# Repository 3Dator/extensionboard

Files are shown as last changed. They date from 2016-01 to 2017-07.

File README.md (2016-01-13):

3Dator extensionboard firmware
======

This repository contains the firmware for our tiny extensionboard that is used to drive the LEDs and both Fans.

Also there is a voltage devider for the 12V Feedback pin of the inductive z probe.

For more information visit our website or wiki:

http://3dator.com

http://wiki.3dator.com

#how to use
If you want to play arrount with the sourcecode on your board you need a ISP Programmer which is supported by Arduino IDE. (e.g. stk 500)

#License
Please note that the material in this repository is licensed with the CC BY-NC-SA

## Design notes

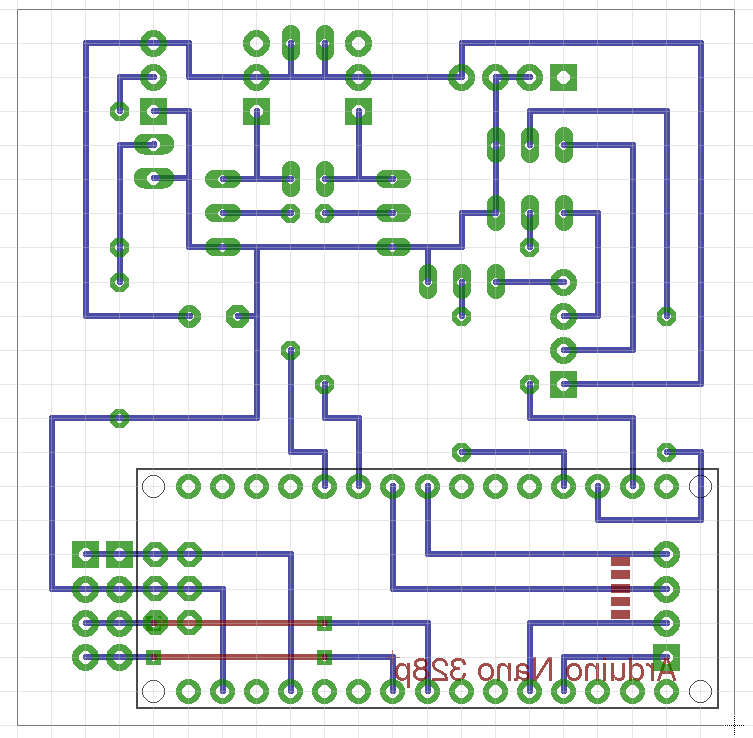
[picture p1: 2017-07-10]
PCB Files/diy PCBs/Analog/diy_analog_Layout_wires_mirrored.png

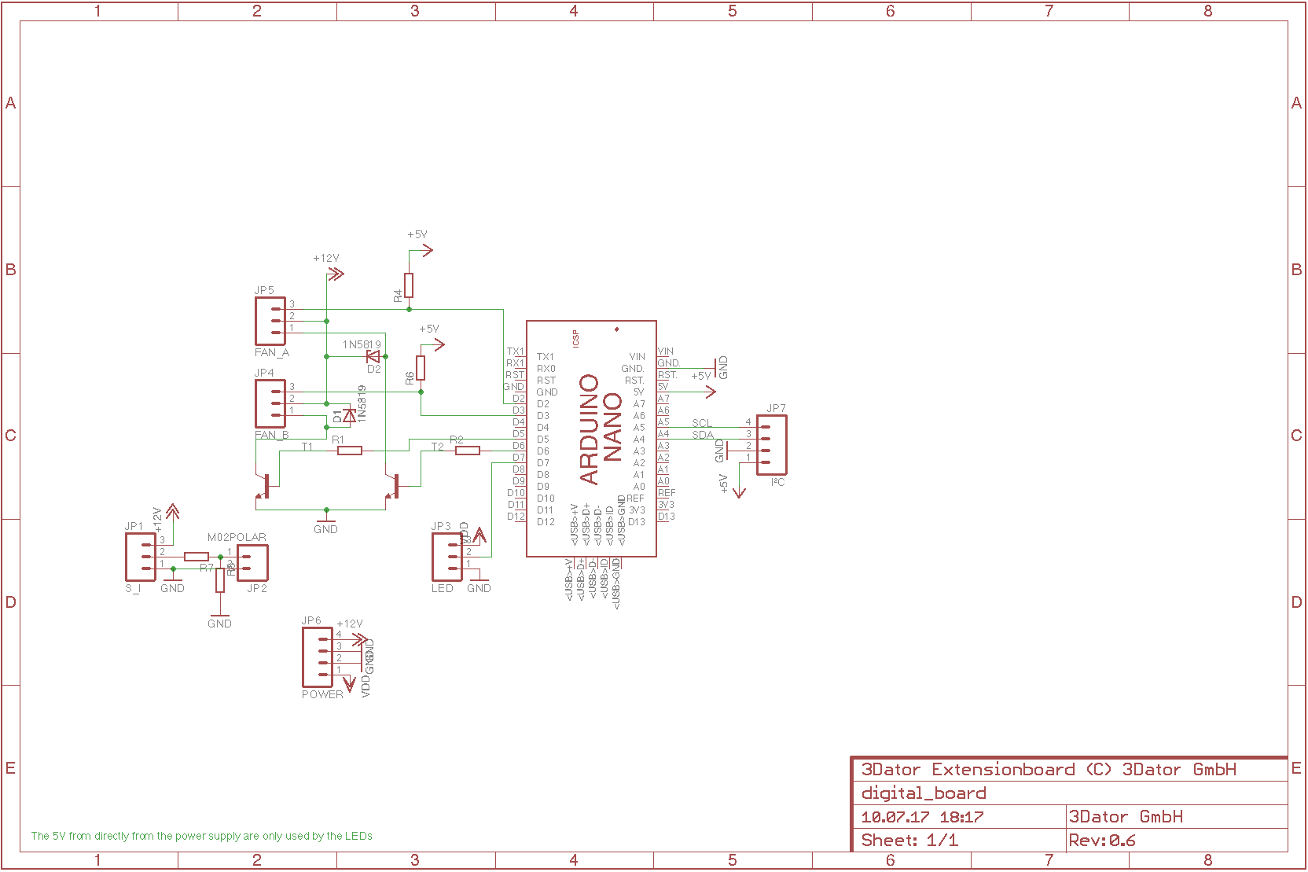
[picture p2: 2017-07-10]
PCB Files/diy PCBs/Digital/diy_digital_pcb.png

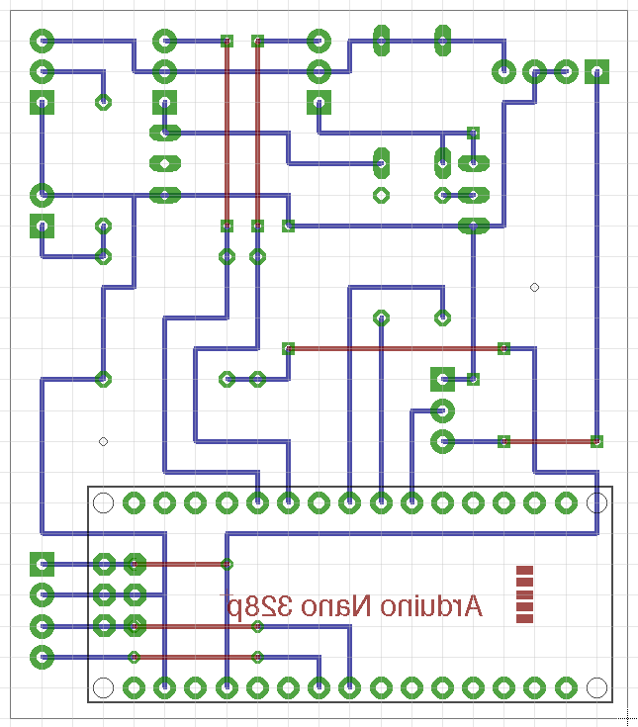
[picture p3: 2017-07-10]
PCB Files/diy PCBs/Digital/diy_digital_Layout_wires_mirrored.png

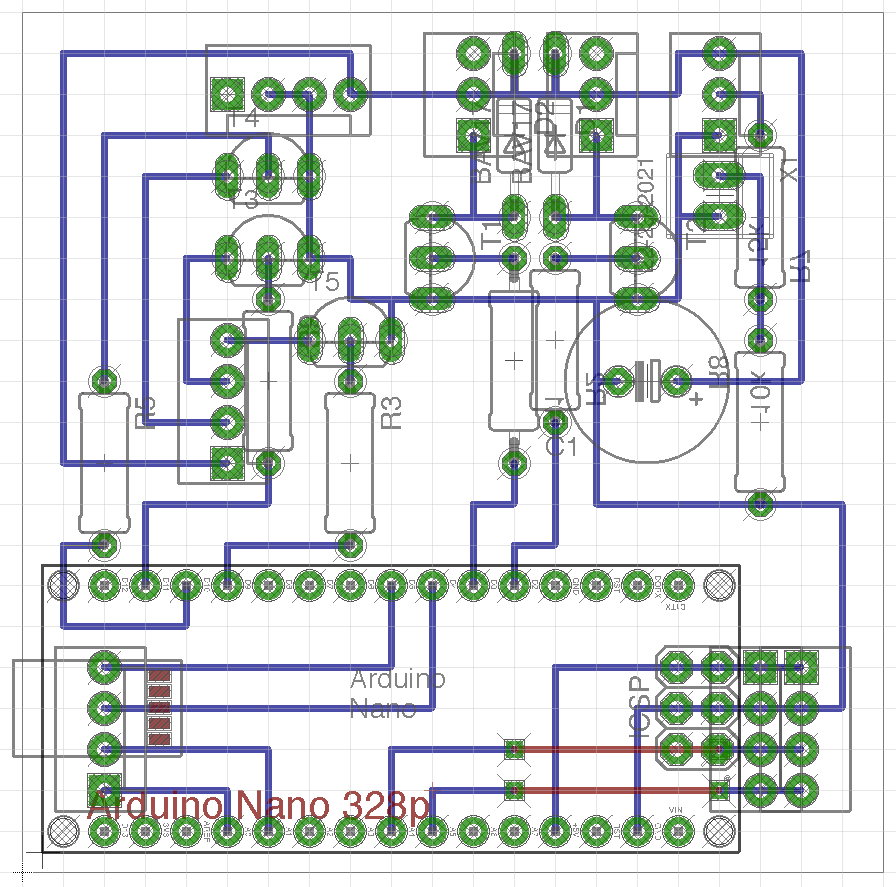
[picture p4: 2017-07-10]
PCB Files/diy PCBs/Analog/diy_analog_Layout.png

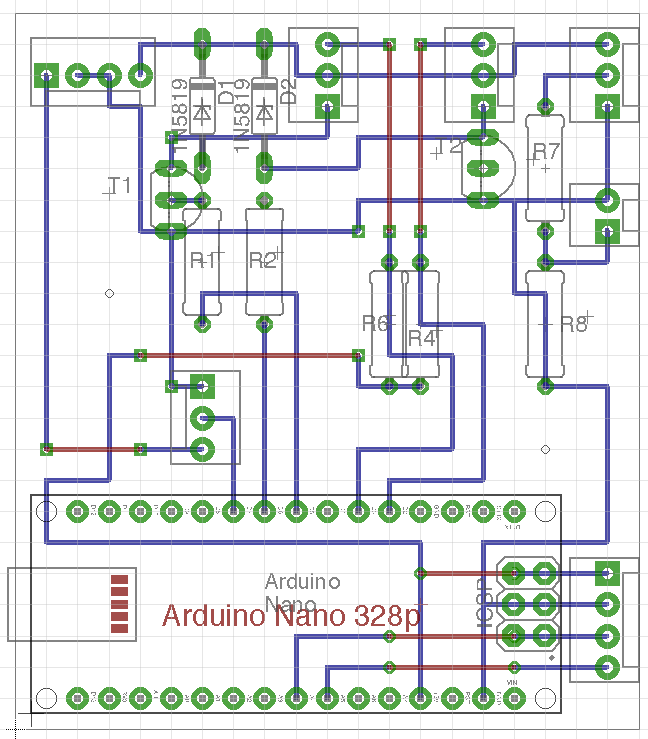
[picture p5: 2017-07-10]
PCB Files/diy PCBs/Digital/diy_digital_Layout.png

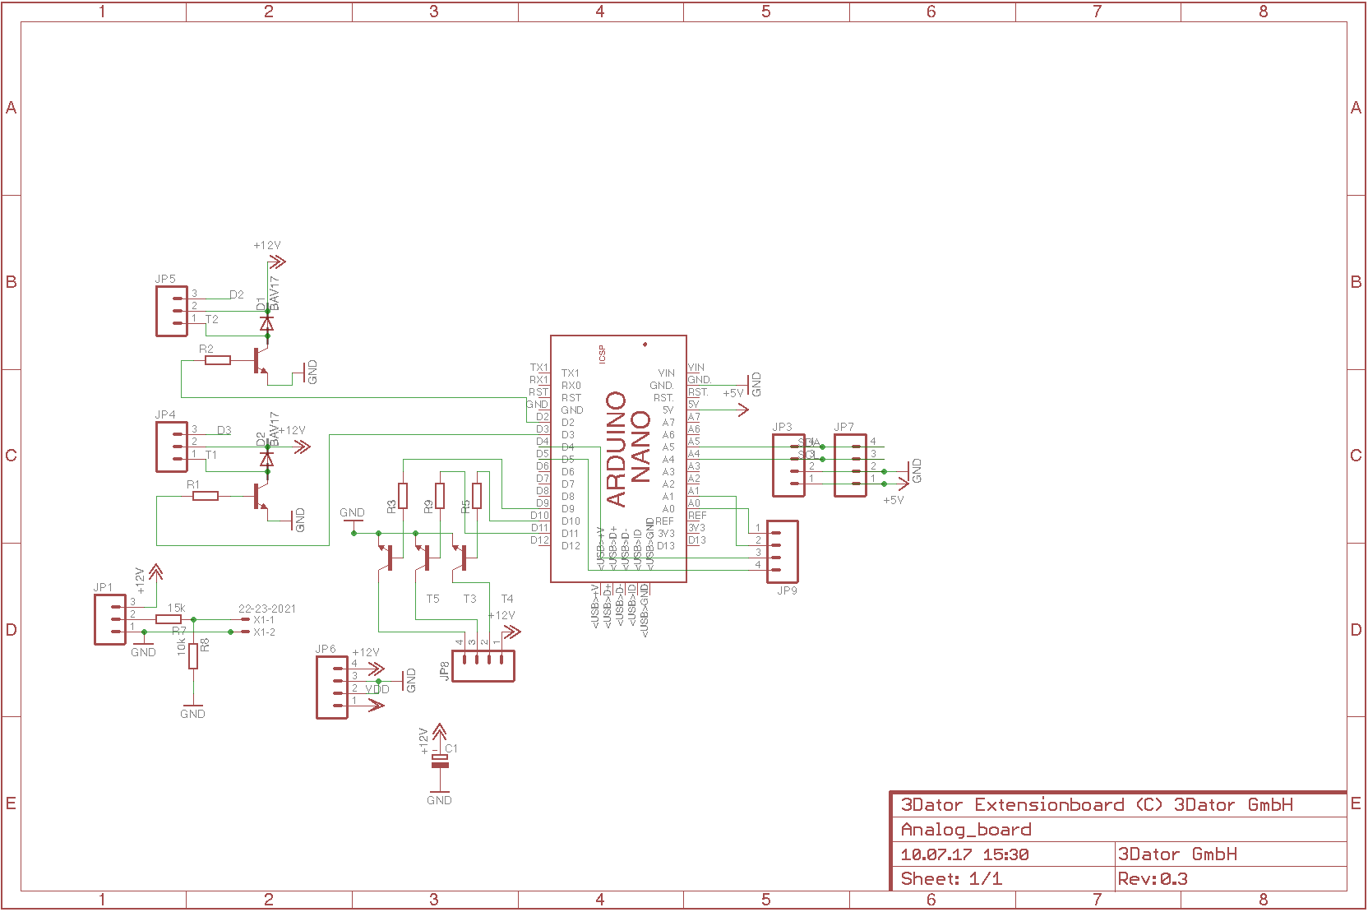
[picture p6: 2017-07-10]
PCB Files/diy PCBs/Analog/diy_analog_pcb.png

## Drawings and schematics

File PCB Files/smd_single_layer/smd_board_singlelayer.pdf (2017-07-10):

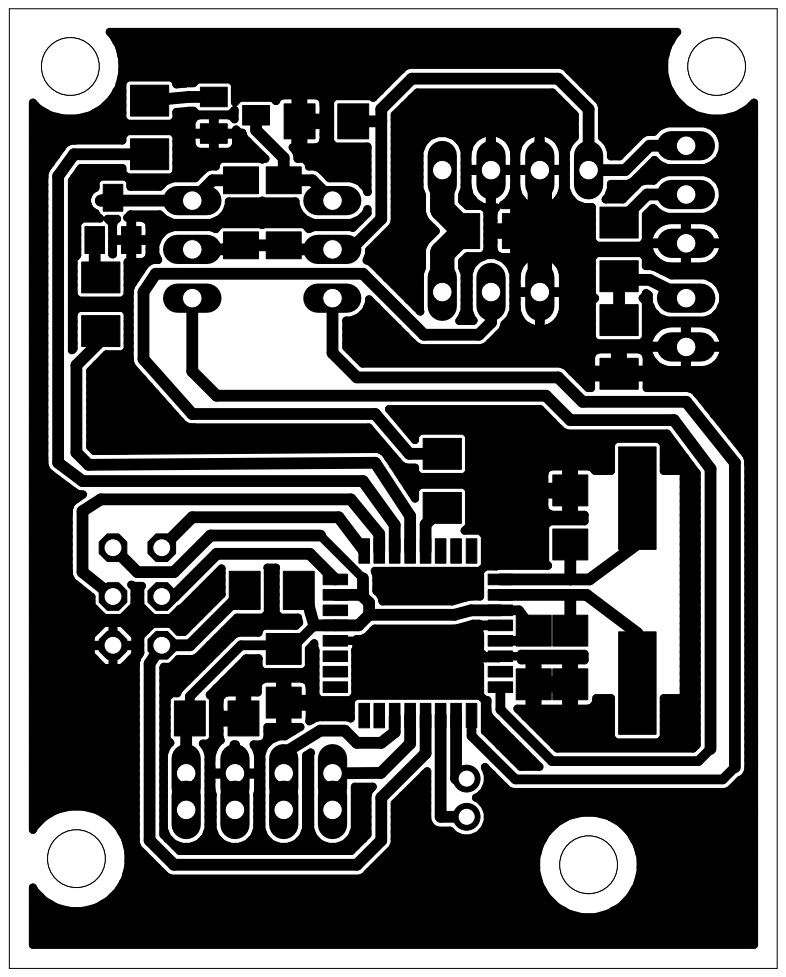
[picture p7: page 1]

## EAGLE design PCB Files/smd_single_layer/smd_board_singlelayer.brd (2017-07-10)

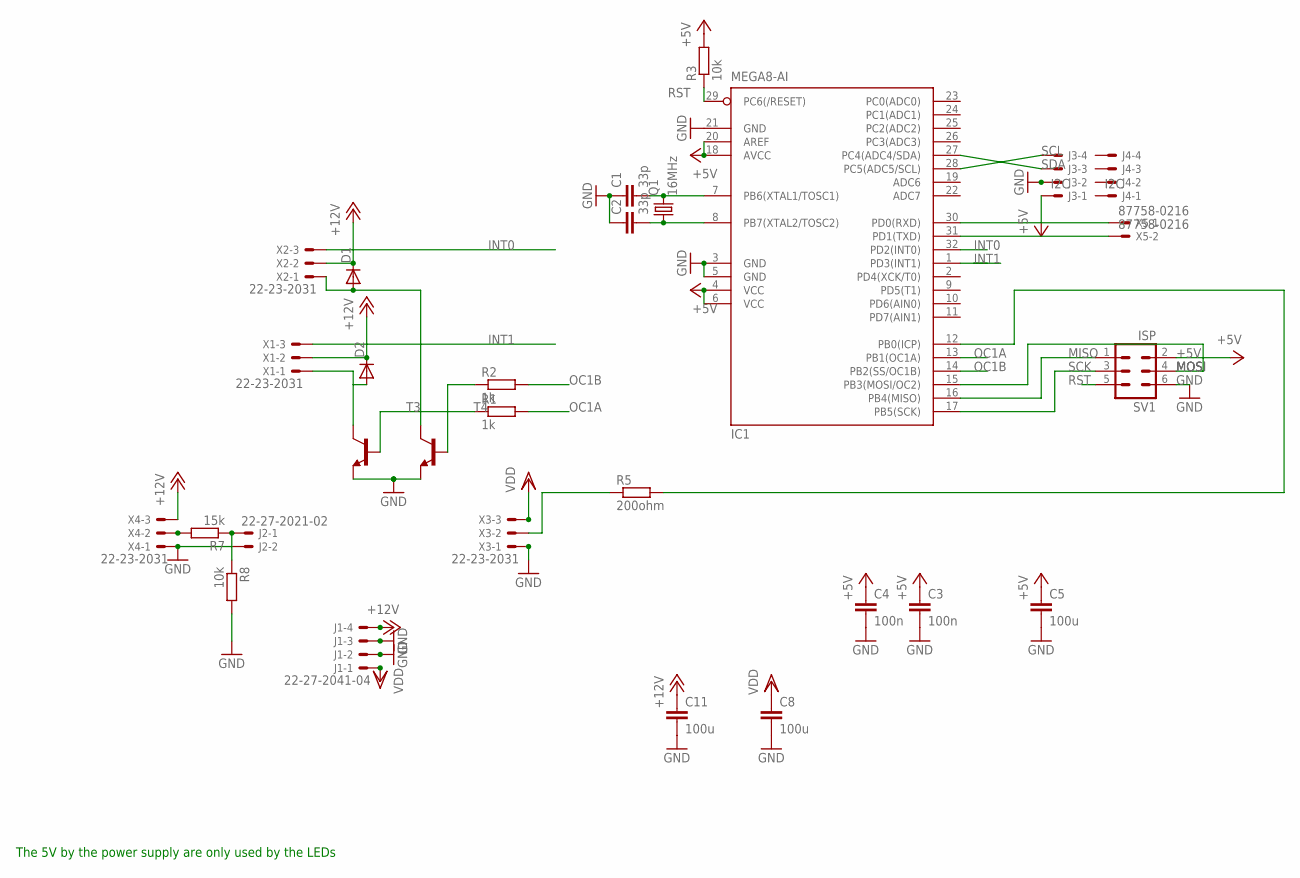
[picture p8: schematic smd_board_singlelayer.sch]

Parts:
C1, C2: 33p; C1206
C3, C4: 100n; C1206
C5, C8, C11: 100u; C1206
D1, D2: DIODE-SOD80C; SOD80C
IC1: MEGA8-AI; TQFP32-08
J1: 22-27-2041-04; 6410-04
J2: 22-27-2021-02; 6410-02
J3, J4: I2C; 6410-04
Q1: 16MHz; HC49UP
R1, R2: 1k; M1206
R3, R8: 10k; M1206
R5: 200ohm; M1206
R7: 15k; M1206
SV1: ISP; ML6
T3, T4: BC808-NPN-SOT23-BEC; SOT23-BEC
X1, X2, X3, X4: 22-23-2031
X5: 87758-0216

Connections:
+5V: C3.1, C4.1, C5.1, IC1.4 (VCC), IC1.6 (VCC), IC1.18 (AVCC), IC1.20 (AREF), J3.1, R3.2, SV1.2
+12V: C11.1, D1.C, D2.C, J1.4, X1.2, X2.2, X4.3
GND: C1.1, C2.1, C3.2, C4.2, C5.2, C8.2, C11.2, IC1.3 (GND), IC1.5 (GND), IC1.21 (GND), J1.2, J1.3, J2.2, J3.2, R8.2, SV1.6, T3.E, T4.E, X3.1, X4.1
INT0: IC1.32 (PD2(INT0)), X2.3
INT1: IC1.1 (PD3(INT1)), X1.3
MISO: IC1.16 (PB4(MISO)), SV1.1
MOSI: IC1.15 (PB3(MOSI/OC2)), SV1.4
unnamed: C1.2, IC1.7 (PB6(XTAL1/TOSC1)), Q1.2
unnamed: D2.A, T3.C, X1.1
unnamed: D1.A, T4.C, X2.1
unnamed: R2.1, T4.B
unnamed: R1.1, T3.B
unnamed: R5.1, X3.2
unnamed: C2.2, IC1.8 (PB7(XTAL2/TOSC2)), Q1.1
unnamed: IC1.30 (PD0(RXD)), X5.1
unnamed: R7.2, X4.2
unnamed: J2.1, R7.1, R8.1
unnamed: IC1.12 (PB0(ICP)), R5.2
unnamed: IC1.31 (PD1(TXD)), X5.2
OC1A: IC1.13 (PB1(OC1A)), R1.2
OC1B: IC1.14 (PB2(SS/OC1B)), R2.2
RST: IC1.29 (PC6(/RESET)), R3.1, SV1.5
SCK: IC1.17 (PB5(SCK)), SV1.3
SCL: IC1.28 (PC5(ADC5/SCL)), J3.4
SDA: IC1.27 (PC4(ADC4/SDA)), J3.3
VDD: C8.1, J1.1, X3.3

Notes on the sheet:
The 5V by the power supply are only used by the LEDs

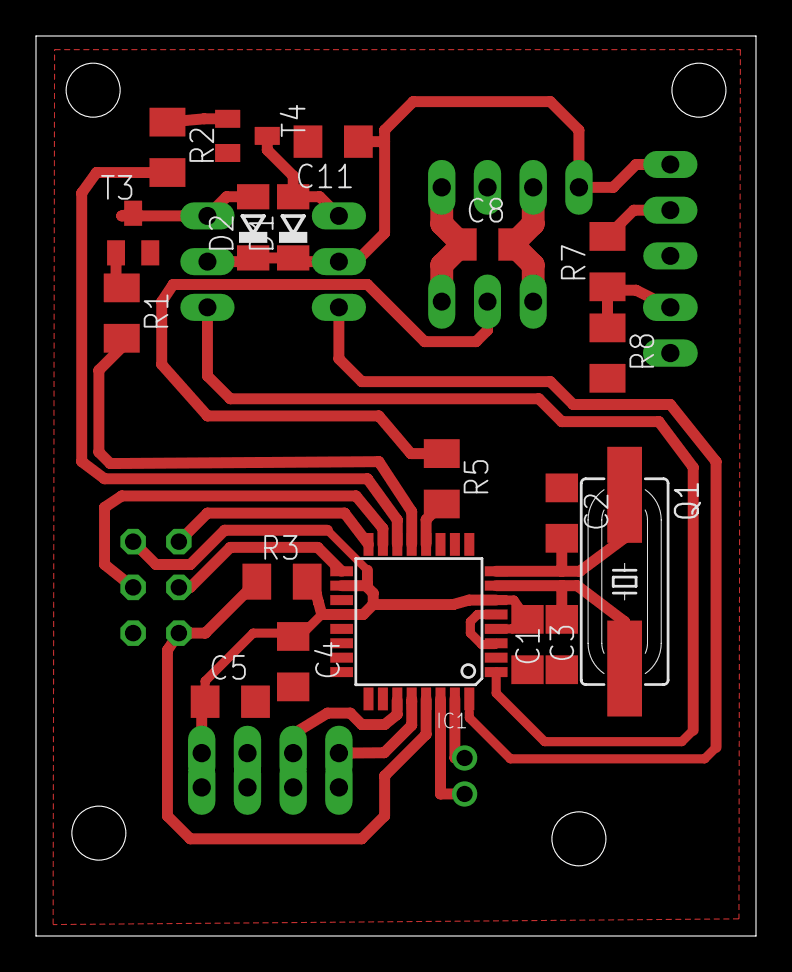
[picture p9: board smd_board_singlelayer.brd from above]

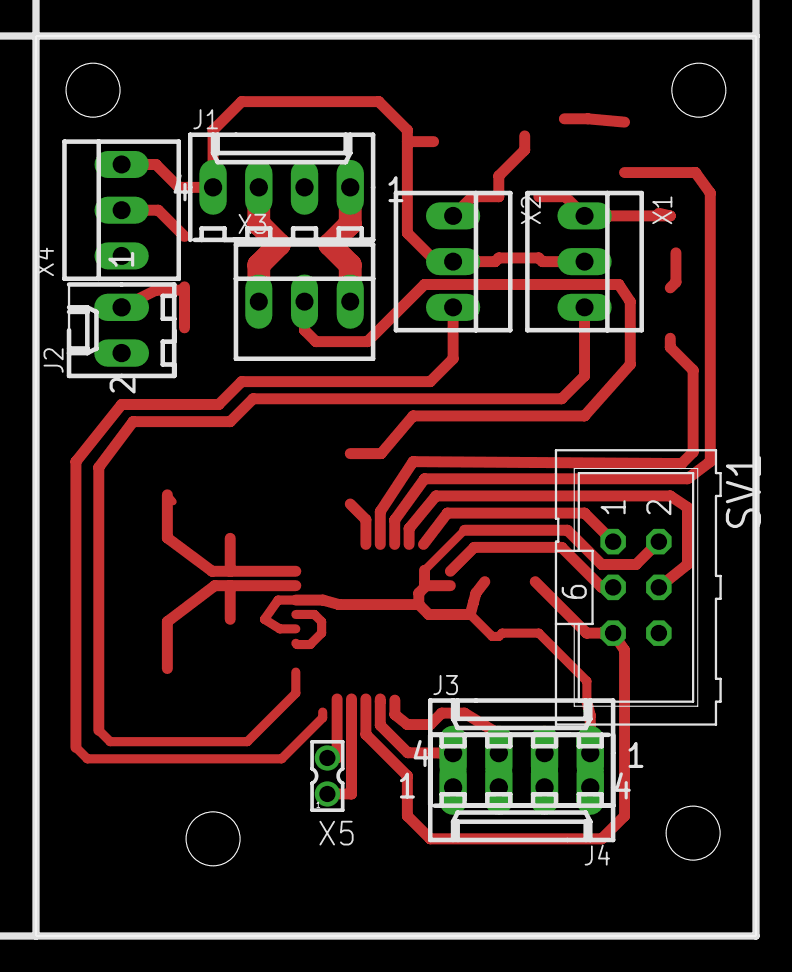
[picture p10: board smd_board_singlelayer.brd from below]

Board: 2 copper layers, 40.0 x 50.0 mm, 29 parts (10 on the bottom side), 26 nets.

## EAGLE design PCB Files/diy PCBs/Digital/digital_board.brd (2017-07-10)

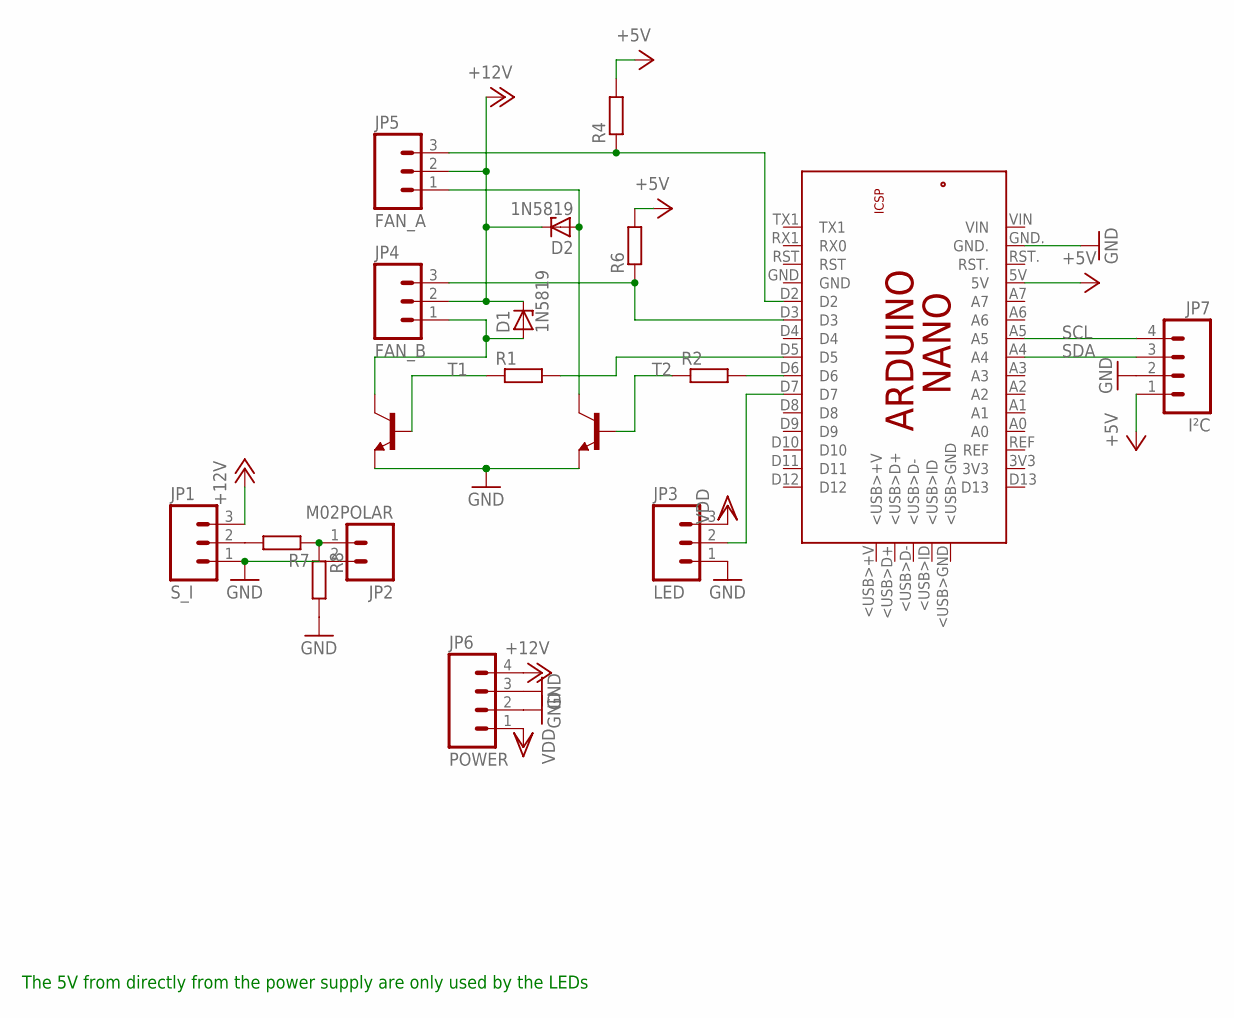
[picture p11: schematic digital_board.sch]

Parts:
D1, D2: 1N5819; DO35Z10
JP1: S_I; MOLEX-1X3
JP2: M02POLAR; MOLEX-1X2
JP3: LED; MOLEX-1X3
JP4: FAN_B; MOLEX-1X3
JP5: FAN_A; MOLEX-1X3
JP6: POWER; MOLEX-1X4
JP7: I²C; MOLEX-1X4
PCB2: ARDUINO_NANO
R1, R2, R4, R6, R7, R8: R-EU_0309/10; 0309/10
T1, T2: BC548-NPN-TO92-CBE; TO92-CBE

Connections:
+5V: JP7.1, PCB2.5V, R4.2, R6.2
+12V: D1.C, D2.C, JP1.3, JP4.2, JP5.2, JP6.4
GND: JP1.1, JP2.2, JP3.1, JP6.2, JP6.3, JP7.2, PCB2.GND., R8.2, T1.E, T2.E
unnamed: D1.A, JP4.1, T1.C
unnamed: D2.A, JP5.1, T2.C
unnamed: R1.1, T1.B
unnamed: PCB2.D5, R1.2
unnamed: PCB2.D6, R2.2
unnamed: JP4.3, PCB2.D3, R6.1
unnamed: JP5.3, PCB2.D2, R4.1
unnamed: JP1.2, R7.2
unnamed: JP2.1, R7.1, R8.1
unnamed: JP3.2, PCB2.D7
SCL: JP7.4, PCB2.A5
SDA: JP7.3, PCB2.A4
VDD: JP3.3, JP6.1

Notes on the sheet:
The 5V from directly from the power supply are only used by the LEDs

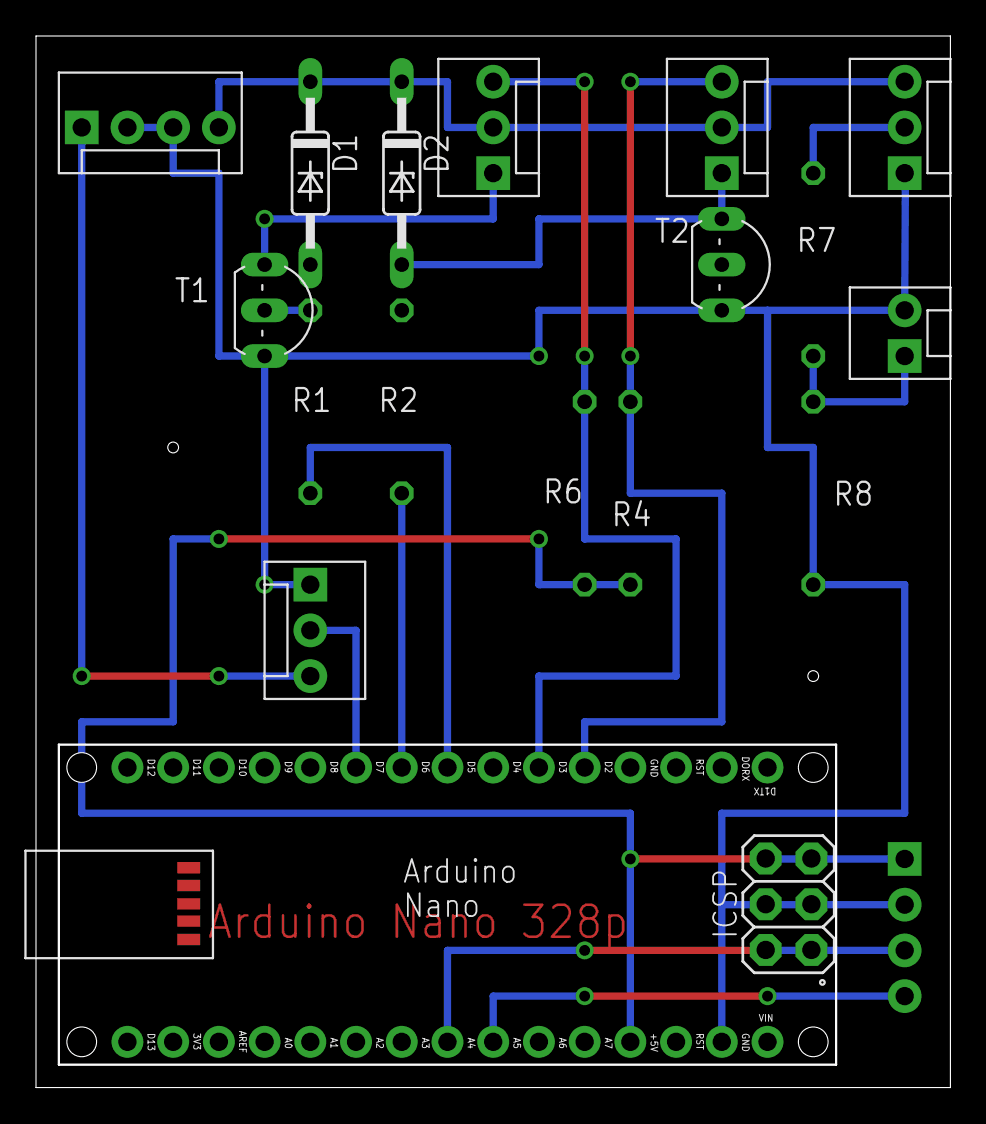
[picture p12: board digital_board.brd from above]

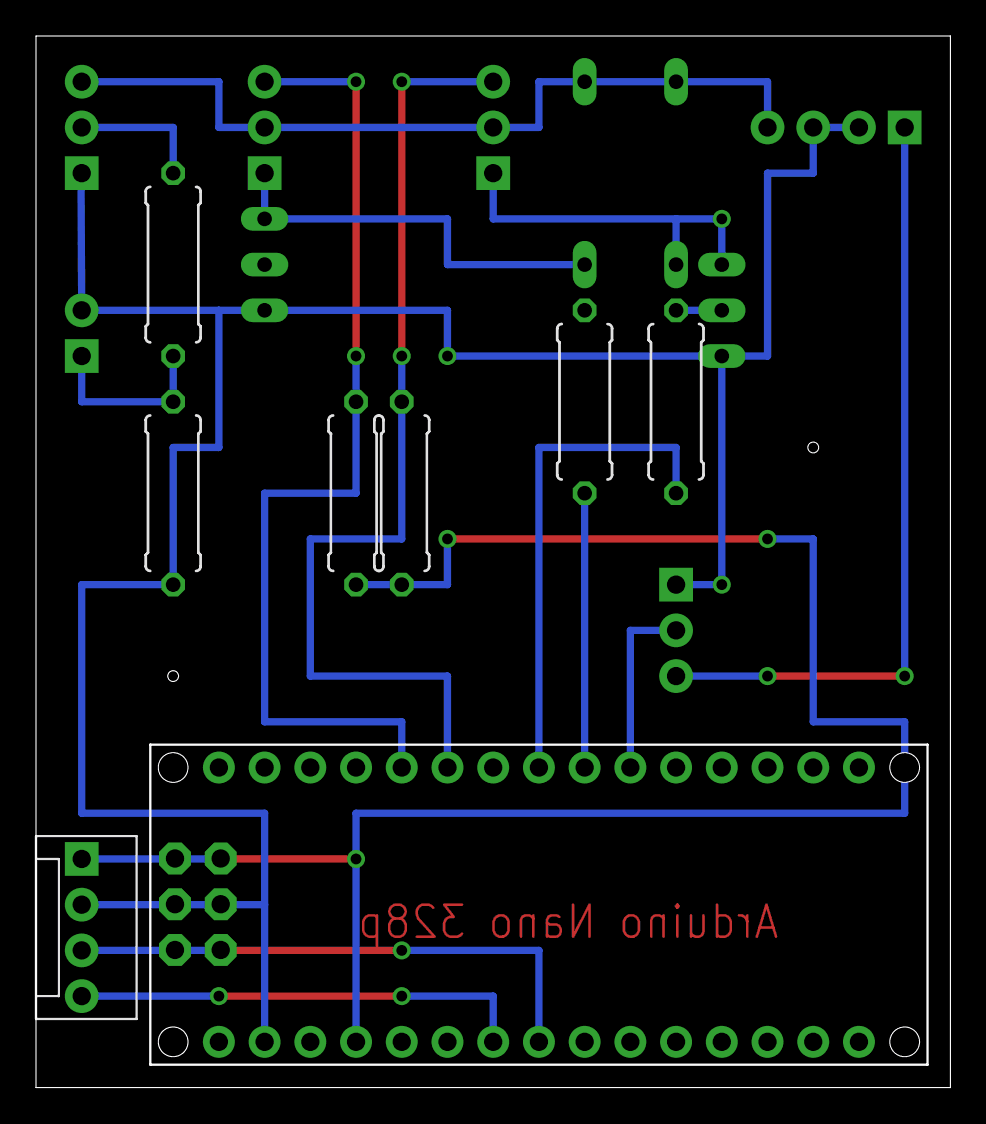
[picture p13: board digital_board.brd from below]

Board: 2 copper layers, 50.8 x 58.4 mm, 18 parts (7 on the bottom side), 16 nets.

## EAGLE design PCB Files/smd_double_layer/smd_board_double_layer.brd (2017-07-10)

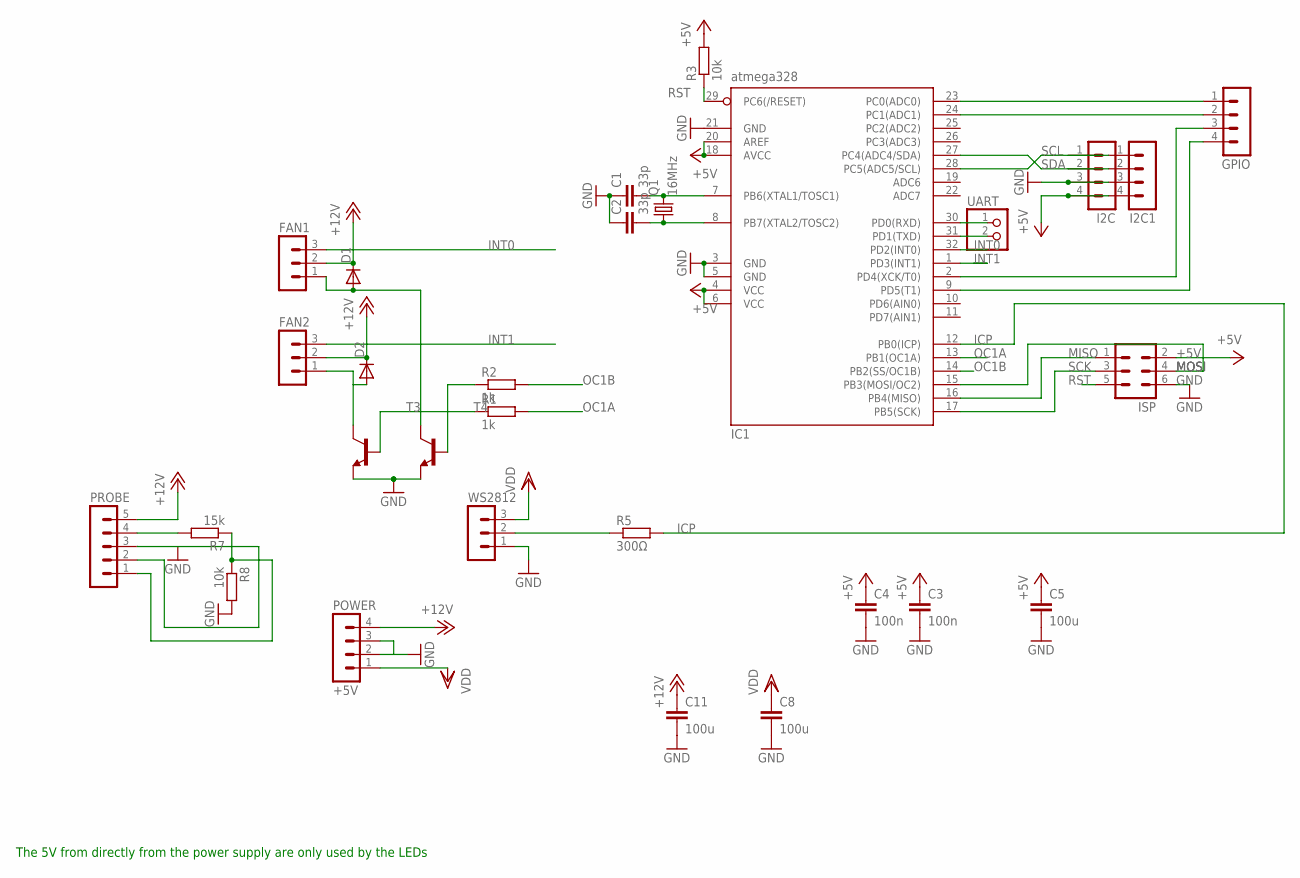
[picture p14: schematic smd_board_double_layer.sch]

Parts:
C1, C2: 33p; C1206
C3, C4: 100n; C1206
C5, C8, C11: 100u; C1206
D1, D2: DIODE-SOD80C; SOD80C
FAN1, FAN2: MA03-1
GPIO: MA04-1
I2C, I2C1: MA04-1
IC1: atmega328; TQFP32-08
ISP: MA03-2
POWER: +5V; MA04-1
PROBE: MA05-1
Q1: 16MHz; HC49UP
R1: 1k; M1206
R2: 1k; R1206
R3, R8: 10k; M1206
R5: 300Ω; R1206
R7: 15k; M1206
T3, T4: BC808-NPN-SOT23-BEC; SOT23-BEC
UART: PINHD-1X2; 1X02
WS2812: MA03-1

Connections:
+5V: C3.1, C4.1, C5.1, I2C.4, I2C1.4, IC1.4 (VCC), IC1.6 (VCC), IC1.18 (AVCC), IC1.20 (AREF), ISP.2, R3.2
+12V: C11.1, D1.C, D2.C, FAN1.2, FAN2.2, POWER.4, PROBE.5
GND: C1.1, C2.1, C3.2, C4.2, C5.2, C8.2, C11.2, I2C.3, I2C1.3, IC1.3 (GND), IC1.5 (GND), IC1.21 (GND), ISP.6, POWER.2, POWER.3, PROBE.2, PROBE.3, R8.2, T3.E, T4.E, WS2812.1
ICP: IC1.12 (PB0(ICP)), R5.2
INT0: FAN1.3, IC1.32 (PD2(INT0))
INT1: FAN2.3, IC1.1 (PD3(INT1))
MISO: IC1.16 (PB4(MISO)), ISP.1
MOSI: IC1.15 (PB3(MOSI/OC2)), ISP.4
unnamed: C1.2, IC1.7 (PB6(XTAL1/TOSC1)), Q1.2
unnamed: D2.A, FAN2.1, T3.C
unnamed: D1.A, FAN1.1, T4.C
unnamed: R2.1, T4.B
unnamed: R1.1, T3.B
unnamed: R5.1, WS2812.2
unnamed: C2.2, IC1.8 (PB7(XTAL2/TOSC2)), Q1.1
unnamed: IC1.30 (PD0(RXD)), UART.1
unnamed: PROBE.4, R7.2
unnamed: GPIO.1, IC1.23 (PC0(ADC0))
unnamed: GPIO.2, IC1.24 (PC1(ADC1))
unnamed: IC1.31 (PD1(TXD)), UART.2
unnamed: GPIO.4, IC1.9 (PD5(T1))
unnamed: PROBE.1, R7.1, R8.1
unnamed: GPIO.3, IC1.2 (PD4(XCK/T0))
OC1A: IC1.13 (PB1(OC1A)), R1.2
OC1B: IC1.14 (PB2(SS/OC1B)), R2.2
RST: IC1.29 (PC6(/RESET)), ISP.5, R3.1
SCK: IC1.17 (PB5(SCK)), ISP.3
SCL: I2C.1, I2C1.1, IC1.28 (PC5(ADC5/SCL))
SDA: I2C.2, I2C1.2, IC1.27 (PC4(ADC4/SDA))
VDD: C8.1, POWER.1, WS2812.3

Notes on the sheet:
The 5V from directly from the power supply are only used by the LEDs

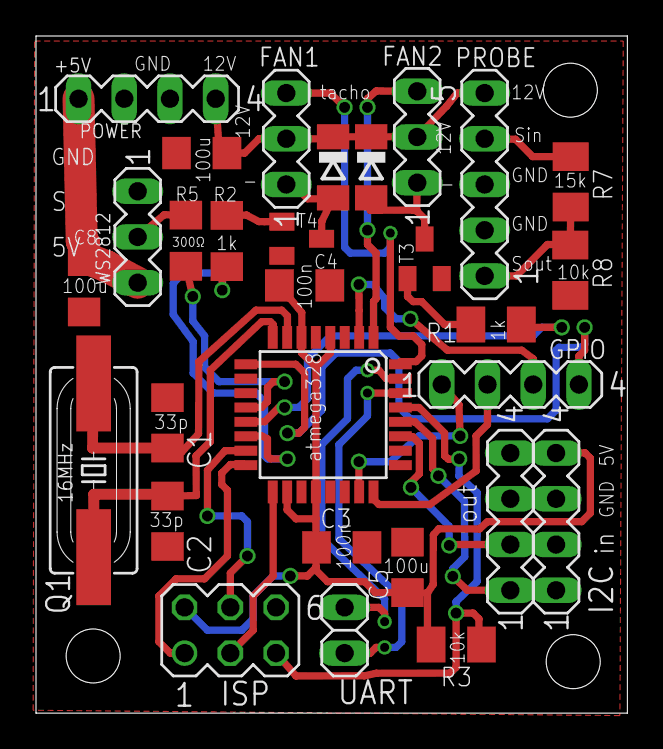
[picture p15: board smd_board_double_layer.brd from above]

Board: 2 copper layers, 32.9 x 37.6 mm, 29 parts (0 on the bottom side), 30 nets.

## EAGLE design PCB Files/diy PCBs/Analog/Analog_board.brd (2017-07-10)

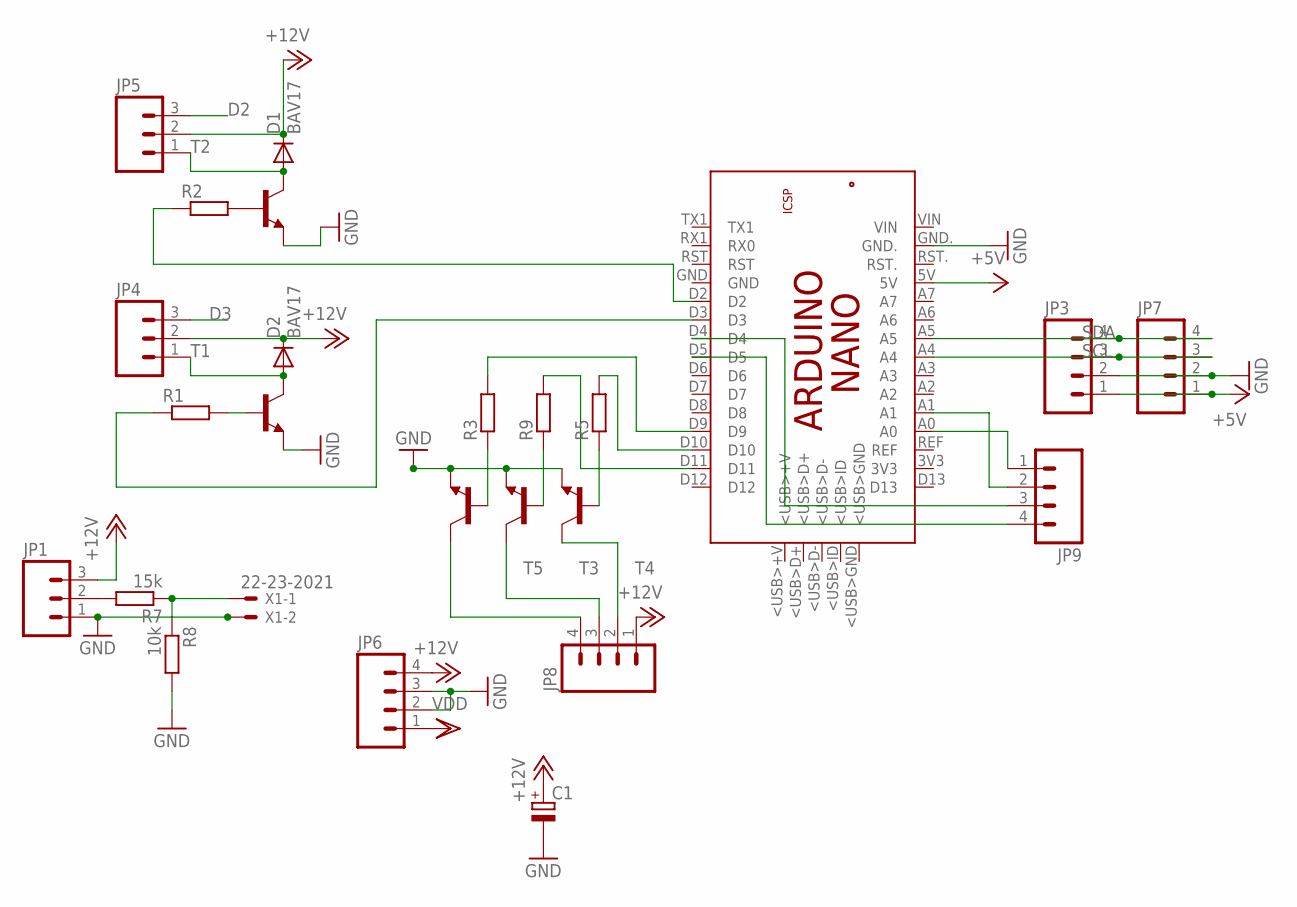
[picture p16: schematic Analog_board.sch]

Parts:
C1: CPOL-EUE3.5-10; E3,5-10
D1, D2: BAV17; DO35-10
JP1, JP4, JP5: M03POLAR; MOLEX-1X3
JP3, JP6, JP7, JP8, JP9: M04POLAR; MOLEX-1X4
PCB2: ARDUINO_NANO
R1: R-EU_0309/12; 0309/12
R2, R3, R5, R9: R-EU_0309/10; 0309/10
R7: 15k; 0309/10
R8: 10k; 0309/10
T1, T2, T3, T4, T5: BC548-NPN-TO92-CBE; TO92-CBE
X1: 22-23-2021

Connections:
+5V: JP3.1, JP7.1, PCB2.5V
+12V: C1.+, D1.C, D2.C, JP1.3, JP4.2, JP5.2, JP6.4, JP8.1
D2: JP5.3
D3: JP4.3
D4: PCB2.D2, R2.1
D5: PCB2.D3, R1.1
GND: C1.-, JP1.1, JP3.2, JP6.2, JP6.3, JP7.2, PCB2.GND., R8.2, T1.E, T2.E, T3.E, T4.E, T5.E, X1.2
unnamed: JP8.4, T5.C
unnamed: R3.1, T5.B
unnamed: D2.A, JP4.1, T1.C
unnamed: D1.A, JP5.1, T2.C
unnamed: R1.2, T1.B
unnamed: R2.2, T2.B
unnamed: JP9.1, PCB2.A0
unnamed: JP9.2, PCB2.A1
unnamed: R5.1, T4.B
unnamed: PCB2.D9, R3.2
unnamed: R9.1, T3.B
unnamed: JP9.3, PCB2.D4
unnamed: JP9.4, PCB2.D5
unnamed: JP1.2, R7.2
unnamed: R7.1, R8.1, X1.1
unnamed: PCB2.D10, R5.2
unnamed: PCB2.D11, R9.2
unnamed: JP8.3, T3.C
unnamed: JP8.2, T4.C
SCL: JP3.4, JP7.4, PCB2.A5
SDA: JP3.3, JP7.3, PCB2.A4
VDD: JP6.1

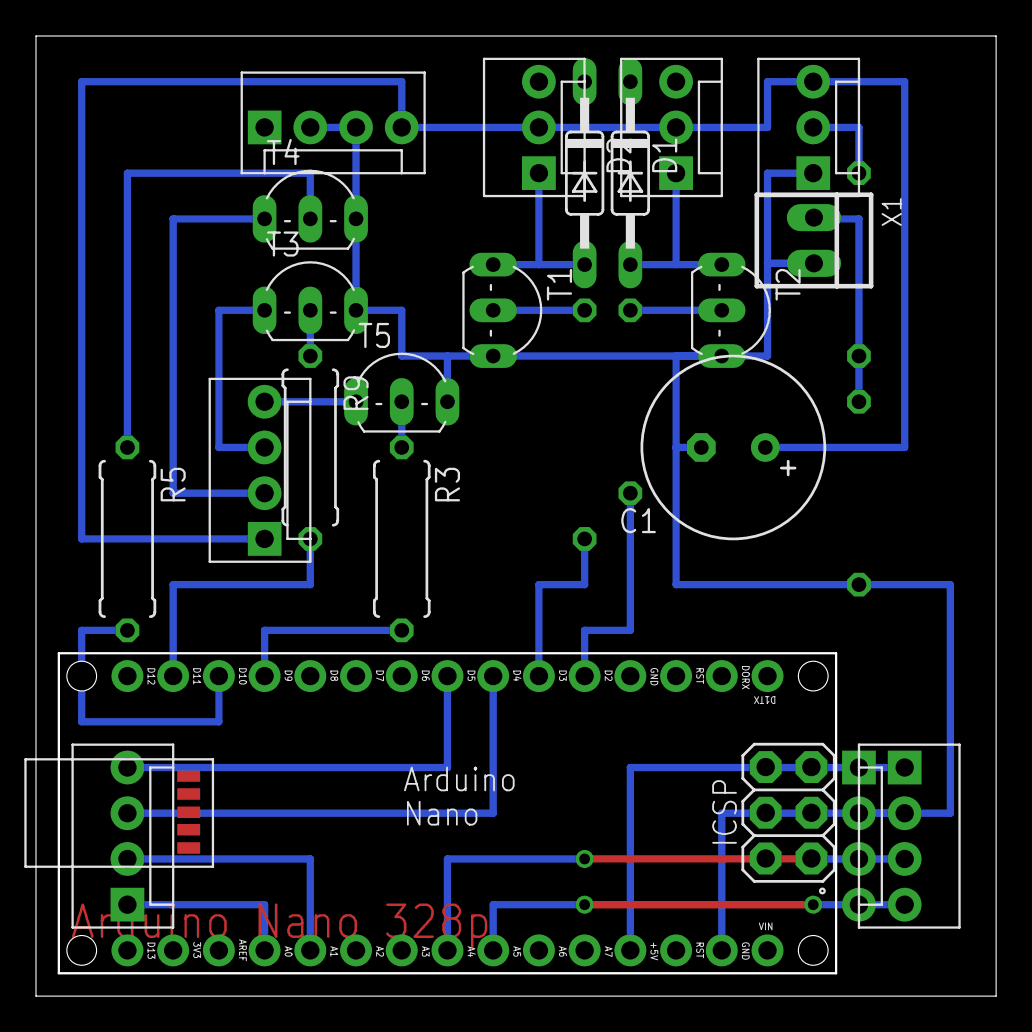
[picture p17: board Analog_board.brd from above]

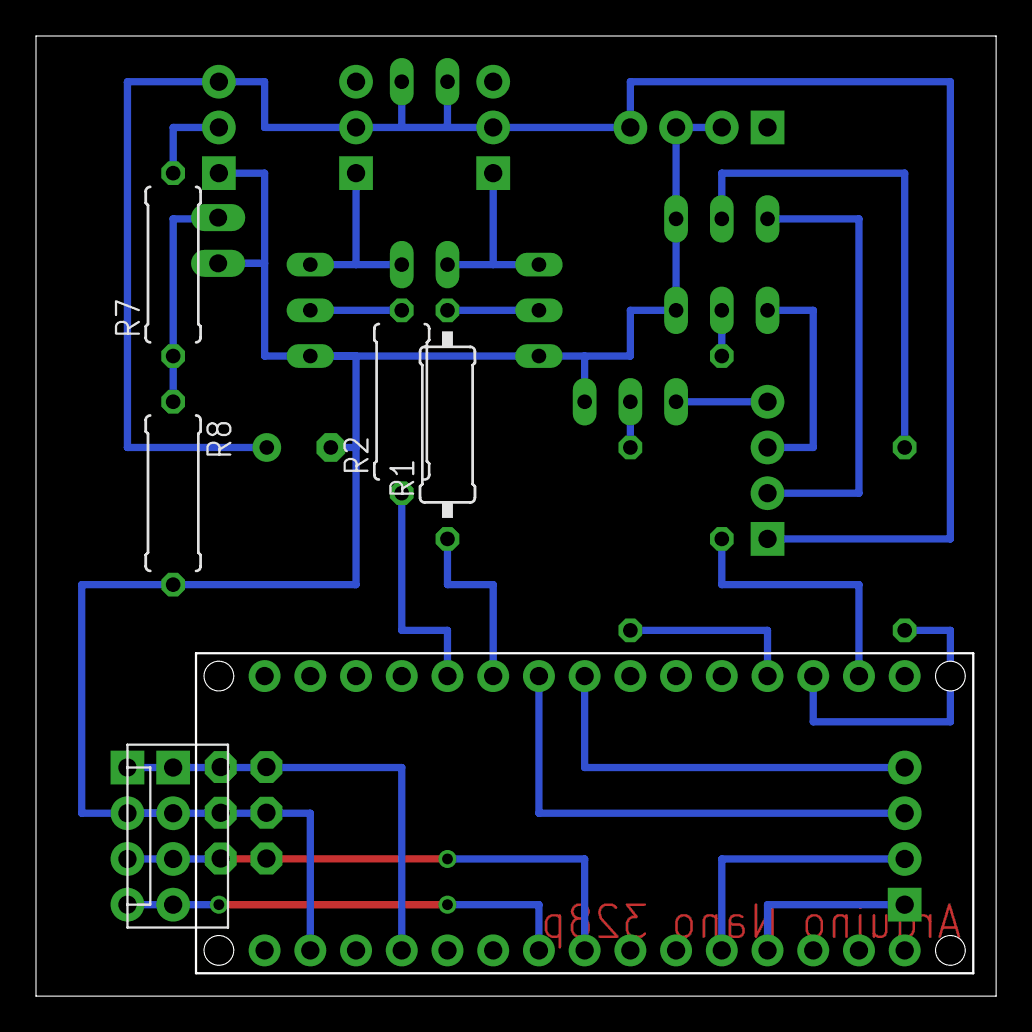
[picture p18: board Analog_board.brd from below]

Board: 2 copper layers, 53.3 x 53.3 mm, 25 parts (5 on the bottom side), 26 nets.

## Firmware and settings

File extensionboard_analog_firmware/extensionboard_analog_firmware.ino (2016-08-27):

#include <Wire.h>
#ifdef __AVR__
  #include <avr/power.h>
#endif

#define PIN_R 11
#define PIN_G 10
#define PIN_B 9

#define FAN_BACK_PIN 2
#define FAN_TOP_PIN 3

byte fan_top = 0;
byte fan_back = 0;

bool rainbow_active = 0;

uint8_t pulse_color_r;
uint8_t pulse_color_g;
uint8_t pulse_color_b;
bool pulse_active = 0;
byte brightness = 255;

//0 means endless and 1 looping stopped all above indicates how often the effect will run
byte rainbow_cycles = 0;
byte pulse_cycles = 0;

uint8_t r=0;
uint8_t g=0;
uint8_t b=0;

byte command;
byte programm;
uint8_t values[6];
bool new_action = 0;

void setup() {
  Wire.begin(4);                // join i2c bus with address #4
  Wire.onReceive(receiveEvent); // register event

  pinMode(FAN_BACK_PIN,OUTPUT);
  pinMode(FAN_TOP_PIN,OUTPUT);

  pinMode(PIN_R,OUTPUT);
  pinMode(PIN_G,OUTPUT);
  pinMode(PIN_B,OUTPUT);

  //turn leds on when printer turns on
  colorFade(255, 255, 255,5);
}

void loop() {
  if(new_action){
    perform_actions(command, programm, values);
  }
  //perform all looping animations. Perform endless if cycles 0 otherwise loop till cycle is 1
  if(rainbow_active && rainbow_cycles != 1){
    if(rainbow_cycles > 1){
      rainbow_cycles--;
    }
    rainbowCycle(10);
  }
  if(pulse_active && pulse_cycles != 1){
    if(pulse_cycles > 1){
      pulse_cycles--;
    }
    colorPulse(pulse_color_r,pulse_color_g,pulse_color_b,5);
  }
}

void receiveEvent(int howMany) {
  new_action = 1;
  command = Wire.read();
  programm = Wire.read();
  uint8_t counter = 0;
  while (Wire.available()) { // loop through all
    values[counter] = Wire.read(); // receive byte
    counter++;
  }
}

//command:
// 1 -> LEDs
// 2 -> FANs
// 3 -> overwrite
// 4 -> stuff

//programm LEDs:
// 1 -> fade LEDs
// 2 -> instant leds
// 3 -> move down
// 4 -> move up
// 5 -> move/wipe leds
// 6 -> jitter LEDs
// 7 -> rainbow (looping)
// 8 -> snake (looping)
// 9 -> pulse (looping)
//10 -> turn off all looping
//11 -> set brightness

//programm FANs:
// 1 -> Fan1 normal mode
// 2 -> Fan2 normal mode
// 3 -> Fan1 PWM mode
// 4 -> Fan2 PWM mode

//programm overwrite (pixels)
// 1 -> single pixel
// 2 -> single pixel stop overwrite
// 3 -> range
// 4 -> range stop overwrite

//programm stuff
// 1 -> Test mode
// 2 -> demo mode

void perform_actions(byte command, byte programm, uint8_t values[3]){
  new_action = 0;
  switch(command){
    //LEDs
    case 1:
      switch(programm){
        case 1:
          colorFade(values[0], values[1], values[2],5);
          break;
        case 2:
          colorInstant(values[0], values[1], values[2]);
          break;
        case 3:
          colorFade(values[0], values[1], values[2],5);
          break;
        case 4:
          colorFade(values[0], values[1], values[2],5);
          break;
        case 5:
          colorInstant(values[0], values[1], values[2]);
          break;
        case 6:
          colorInstant(values[0], values[1], values[2]);
          break;
        case 7:
          rainbow_cycles = values[3];
          if(rainbow_cycles > 0) rainbow_cycles++;
          turn_looping_off();
          rainbow_active = 1;
          break;
        case 9:
          pulse_cycles = values[3];
          if(pulse_cycles > 0) pulse_cycles++;
          turn_looping_off();
          pulse_color_r = values[0];
          pulse_color_g = values[1];
          pulse_color_b = values[2];
          pulse_active = 1;
          break;
        case 10:
          turn_looping_off();
          break;
        case 11:
          brightness = values[2];
          colorInstant(r, g, b);
          break;
      }
      if(programm <= 6){
        r = values[0];
        g = values[1];
        b = values[2];
      }
      break;
    //FANs
    case 2:
      switch(programm){
        case 1:
          setFan(1,values[0]);
          break;
        case 2:
          setFan(0,values[0]);
          break;
      }
      break;
    //test programms
    case 4:
      switch(programm){
        case 1:
          colorInstant(0,0,0);
          r = 0;
          g = 0;
          b = 0;
          setFan(0,255);
          delay(1000);
          setFan(0,0);
          delay(1000);
          setFan(1,255);
          delay(1000);
          setFan(1,0);
          delay(1000);
          colorInstant(255,0,0);
          delay(1000);
          colorInstant(0,255,0);
          delay(1000);
          colorInstant(0,0,255);
          delay(1000);
          break;
        case 2:
          setFan(0,200);
          setFan(1,150);
          delay(1000);
          rainbowCycle(10);
          setFan(0,0);
          setFan(1,0);
          break;
      }
      break;
  }
}

//turn all looping off
void turn_looping_off(){
  pulse_active = 0;
  rainbow_active = 0;
  colorInstant(r, g, b);
}

//use this function to manage the brightness
void set_color(uint8_t r,uint8_t g,uint8_t b){
  analogWrite(PIN_R,(r/255.0)*brightness);
  analogWrite(PIN_G,(g/255.0)*brightness);
  analogWrite(PIN_B,(b/255.0)*brightness);
}

void colorPulse(uint8_t color_r,uint8_t color_g,uint8_t color_b,uint8_t wait){
  uint8_t old_r;
  uint8_t old_g;
  uint8_t old_b;
  colorFade(color_r,color_g,color_b, wait);
  old_r = r;
  old_g = g;
  old_b = b;
  colorFade(old_r,old_g,old_b, wait);
  r = old_r;
  g = old_g;
  b = old_b;
}

void colorFade(uint8_t new_r, uint8_t new_g, uint8_t new_b, uint8_t wait) {
  uint8_t steps = 100;
  for(uint8_t s = 0;s<=steps;s++){
    set_color(((new_r-r)/(float)steps)*s+r, ((new_g-g)/(float)steps)*s+g, ((new_b-b)/(float)steps)*s+b);
    delay(wait);
  }
}

void colorInstant(uint8_t new_r, uint8_t new_g, uint8_t new_b) {
  set_color(new_r ,new_g ,new_b);
}

void setFan(uint8_t fan,uint8_t fanspeed) {
switch (fan){
  case 0:
    if(fanspeed>0 && fanspeed < 150 && fan_back == 0){
      analogWrite(FAN_BACK_PIN,255);
      delay(1000);
      analogWrite(FAN_BACK_PIN,fanspeed);
    }else{
      analogWrite(FAN_BACK_PIN,fanspeed);
    }
    fan_back = fanspeed;
    break;
  case 1:
    if(fanspeed>0 && fanspeed < 150 && fan_top == 0){
      analogWrite(FAN_TOP_PIN,255);
      delay(1000);
      analogWrite(FAN_TOP_PIN,fanspeed);
    }else{
      analogWrite(FAN_TOP_PIN,fanspeed);
    }
    fan_top = fanspeed;
    break;
  }
}

void rainbowCycle(uint8_t wait) {
  byte rgbColour[3];
  
  // Start off with red.
  rgbColour[0] = 255;
  rgbColour[1] = 0;
  rgbColour[2] = 0;  

  // Choose the colours to increment and decrement.
  for (int decColour = 0; decColour < 3; decColour += 1) {
    int incColour = decColour == 2 ? 0 : decColour + 1;

    // cross-fade the two colours.
    for(int i = 0; i < 255; i += 1) {
      rgbColour[decColour] -= 1;
      rgbColour[incColour] += 1;
      
      set_color(rgbColour[0], rgbColour[1], rgbColour[2]);
      delay(wait);
    }
  }
}

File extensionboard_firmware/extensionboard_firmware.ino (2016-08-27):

#include <Wire.h>
#include <Adafruit_NeoPixel.h>
#ifdef __AVR__
  #include <avr/power.h>
#endif

#define PIN 8
#define PIXEL 54

#define FAN_BACK OCR1B
#define FAN_BACK_PIN 10

#define FAN_TOP OCR1A
#define FAN_TOP_PIN 9

//manage pixel
bool pixel_overwrite[PIXEL];
uint32_t pixel_color[PIXEL];

uint32_t snake_color;
bool snake_active = 0;


bool rainbow_active = 0;


uint8_t pulse_color_r;
uint8_t pulse_color_g;
uint8_t pulse_color_b;
bool pulse_active = 0;

//0 means endless and 1 looping stopped all above indicates how often the effect will run
byte snake_cycles = 0;
byte rainbow_cycles = 0;
byte pulse_cycles = 0;

uint8_t r=0;
uint8_t g=0;
uint8_t b=0;

byte command;
byte programm;
uint8_t values[6];
bool new_action = 0;

Adafruit_NeoPixel strip = Adafruit_NeoPixel(PIXEL, PIN, NEO_GRB + NEO_KHZ800);

void setup() {
  pinMode(FAN_BACK_PIN,OUTPUT);
  pinMode(FAN_TOP_PIN,OUTPUT);

  TCCR1A |= (1<< WGM10) | (1 << COM1A1) | (1 << COM1B1);
  strip.begin();
  strip.show(); // Initialize all pixels to 'off'
  Wire.begin(4);                // join i2c bus with address #4
  Wire.onReceive(receiveEvent); // register event
}

void loop() {
  if(new_action){
    perform_actions(command, programm, values);
  }
  //perform all looping animations. Perform endless if cycles 0 otherwise loop till cycle is 1
  if(snake_active && snake_cycles != 1){
    if(snake_cycles > 1){
      snake_cycles--;
    }
    colorSnake(snake_color,20,10);
    delay(100);
  }
  if(rainbow_active && rainbow_cycles != 1){
    if(rainbow_cycles > 1){
      rainbow_cycles--;
    }
    rainbowCycle(10);
  }
  if(pulse_active && pulse_cycles != 1){
    if(pulse_cycles > 1){
      pulse_cycles--;
    }
    colorPulse(pulse_color_r,pulse_color_g,pulse_color_b,5);
  }
}

void receiveEvent(int howMany) {
  new_action = 1;
  command = Wire.read();
  programm = Wire.read();
  uint8_t counter = 0;
  while (Wire.available()) { // loop through all
    values[counter] = Wire.read(); // receive byte
    counter++;
  }
}

//command:
// 1 -> LEDs
// 2 -> FANs
// 3 -> overwrite
// 4 -> stuff

//programm LEDs:
// 1 -> fade LEDs
// 2 -> instant leds
// 3 -> move down
// 4 -> move up
// 5 -> move/wipe leds
// 6 -> jitter LEDs
// 7 -> rainbow (looping)
// 8 -> snake (looping)
// 9 -> pulse (looping)
//10 -> turn off all looping
//11 -> set brightness

//programm FANs:
// 1 -> Fan1 normal mode
// 2 -> Fan2 normal mode
// 3 -> Fan1 PWM mode
// 4 -> Fan2 PWM mode

//programm overwrite (pixels)
// 1 -> single pixel
// 2 -> single pixel stop overwrite
// 3 -> range
// 4 -> range stop overwrite

//programm stuff
// 1 -> Test mode
// 2 -> demo mode

void perform_actions(byte command, byte programm, uint8_t values[3]){
  new_action = 0;
  switch(command){
    //LEDs
    case 1:
      switch(programm){
        case 1:
          colorFade(values[0], values[1], values[2],0);
          break;
        case 2:
          colorInstant(strip.Color(values[0], values[1], values[2]));
          break;
        case 3:
          colorDown(strip.Color(values[0], values[1], values[2]),20);
          break;
        case 4:
          colorUp(strip.Color(values[0], values[1], values[2]),20);
          break;
        case 5:
          colorWipe(strip.Color(values[0], values[1], values[2]),20);
          break;
        case 6:
          colorJitter(strip.Color(values[0], values[1], values[2]),20);
          break;
        case 7:
          rainbow_cycles = values[3];
          if(rainbow_cycles > 0) rainbow_cycles++;
          turn_looping_off();
          rainbow_active = 1;
          break;
        case 8:
          snake_cycles = values[3];
          if(snake_cycles > 0) snake_cycles++;
          turn_looping_off();
          snake_color = strip.Color(values[0], values[1], values[2]);
          snake_active = 1;
          break;
        case 9:
          pulse_cycles = values[3];
          if(pulse_cycles > 0) pulse_cycles++;
          turn_looping_off();
          pulse_color_r = values[0];
          pulse_color_g = values[1];
          pulse_color_b = values[2];
          pulse_active = 1;
          break;
        case 10:
          turn_looping_off();
          break;
        case 11:
          strip.setBrightness(values[2]);
          strip.show();
          break;
      }
      if(programm <= 6){
        r = values[0];
        g = values[1];
        b = values[2];
      }
      break;
    //FANs
    case 2:
      switch(programm){
        case 1:
          setFan(0,values[0]);
          break;
        case 2:
          setFan(1,values[0]);
          break;
      }
      break;
    //overwrite pixels
    case 3:
      switch(programm){
        case 1:
          if(values[0] <= PIXEL){
            //set pixel to overwrite with which color
            pixel_overwrite[values[0]] = 1;
            pixel_color[values[0]] = strip.Color(values[1], values[2], values[3]);
            set_overwrite_pixel();
          }
          break;
        case 2:
          if(values[0] <= PIXEL){
            //set pixel to overwrite with which color
            pixel_overwrite[values[0]] = 0;
            set_overwrite_pixel();
          }
          break;
        case 3:
          if(values[0] <= PIXEL and values[1] <= PIXEL and values[0] <= values[1]){
            for(uint8_t i = values[0];i<=values[1];i++){
              //set pixel to overwrite with which color
              pixel_overwrite[i] = 1;
              pixel_color[i] = strip.Color(values[2], values[3], values[4]);
            }
            set_overwrite_pixel();
          }
          break;
        case 4:
          if(values[0] <= PIXEL and values[1] <= PIXEL and values[0] <= values[1]){
            for(uint8_t i = values[0];i<=values[1];i++){
              //set pixel to overwrite with which color
              pixel_overwrite[i] = 0;
            }
            set_overwrite_pixel();
          }
          break;
      }
      break;
    //test programms
    case 4:
      switch(programm){
        case 1:
          colorInstant(0);
          r = 0;
          g = 0;
          b = 0;
          setFan(0,255);
          delay(1000);
          setFan(0,0);
          delay(1000);
          setFan(1,255);
          delay(1000);
          setFan(1,0);
          delay(1000);
          colorSnake(strip.Color(255,0,0),50,1);
          colorSnake(strip.Color(0,255,0),50,1);
          colorSnake(strip.Color(0,0,255),50,1);
          colorInstant(strip.Color(255,0,0));
          delay(1000);
          colorInstant(strip.Color(0,255,0));
          delay(1000);
          colorInstant(strip.Color(0,0,255));
          delay(1000);
          break;
        case 2:
          setFan(0,200);
          setFan(1,150);
          colorUp(strip.Color(0,0,255),20);
          colorDown(strip.Color(0,255,0),20);
          colorUp(strip.Color(255,0,0),20);
          colorDown(strip.Color(255,255,0),20);
          colorUp(strip.Color(255,255,255),20);
          colorDown(strip.Color(0,255,255),20);
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

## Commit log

2016-01-07 using real pwm
2016-01-09 adde jitter mode
2016-01-10 added overwrite for every led
2016-01-26 fixed fan issue
2016-08-05 added code for analog board (untested)
2016-08-27 fixed rainbow on analog board
    [extensionboard_analog_firmware.ino]
2017-07-10 added PCB files for the Extension Board
    There is a PCB file for DIY PCBs for both Analog and Digital LED Stripes
    [Analog_board.brd, Analog_board.sch, digital_board.brd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]
2017-07-10 made fixed a small bug and changed diode parameters
    [digital_board.brd, digital_board.sch]
2017-07-10 updated files
    [smd_board_singlelayer.brd]

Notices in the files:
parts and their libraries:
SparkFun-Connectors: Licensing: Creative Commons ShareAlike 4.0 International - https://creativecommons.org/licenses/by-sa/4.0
